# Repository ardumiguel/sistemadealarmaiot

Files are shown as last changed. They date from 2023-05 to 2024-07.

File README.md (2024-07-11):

# Sistema de Alarma IoT

Proyecto presentado en la **Feria Andaluza de Tecnología 2023** y en la **25ª Feria de la Ciencia** del Parque de las Ciencias. Realizado  en el curso de 1 de bachillerato en el IES Alquivira.



El sistema de alarma IoT se compone de cuatro módulos inalámbricos. Cada uno de ellos cuenta con un ESP32 que, a través del protocolo de comunicación inalámbrica “ESP-now”, es capaz de comunicarse con el resto de módulos. Estos son: sensor inalámbrico de puerta o ventana, panel de control, módulo de cámara con sensor de movimiento, y sensor inalámbrico de movimiento. Cabe destacar que los modulos de sensor de movimiento y de puerta o ventana son tan eficientes en cuanto a términos energéticos que su duración de batería es de 18 meses.

## Características

- Control vía Telegram (notificaciones instantáneas, control desde cualquier parte del mundo)
- Lector óptico de huella dactilar
- Módulo de cámara con lente ultra gran angular
- Larga duración de la bateria de los módulos inalámbricos

## Funcionamiento
El funcionamiento está diseñado para que el manejo de la alarma por parte del usuario sea simple e intuitivo.

La alarma puede ser activada vía Telegram, que es la plataforma mediante la cual el sistema notifica al usuario y le envía fotos, o bien manualmente desde el módulo principal. Una vez el sistema está activo, al detectar algún movimiento o la apertura de una puerta, notifica de inmediato al usuario indicando el motivo de la alerta y acompañando el mensaje con una fotografía. 

Para desactivar el sistema, el usuario puede colocar su dedo (previamente registrado) en el lector de huellas incorporado en el módulo principal o en su defecto, enviar un comando por Telegram. El usuario también puede solicitar una fotografía o información acerca del sistema (niveles de batería, estado del sistema, estado de las puertas) en cualquier momento a través de Telegram.
## Librerías necesarias

- [AsyncTelegram2](https://github.com/cotestatnt/AsyncTelegram2)
- [Keypad](https://github.com/Chris--A/Keypad)
- [Adafruit_NeoPixel](https://github.com/adafruit/Adafruit_NeoPixel)
- [Adafruit-Fingerprint-Sensor-Library](https://github.com/adafruit/Adafruit-Fingerprint-Sensor-Library)

## Autor

- [@ardumiguel](https://github.com/ardumiguel)

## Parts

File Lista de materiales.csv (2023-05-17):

Materiales necesarios para el sistema de alarma IoT
Producto | Cantidad | Enlace
ESP32 DEVKIT C - "ESP-32 38 PIN" | 3 | https://www.aliexpress.com/item/32864722159.html
ESP32 CAM | 1 | https://www.aliexpress.com/item/1005003804757059.html
Porgramador micro usb ESP32 CAM | 1 | https://www.aliexpress.com/item/1005003804757059.html
Sensor PIR HC-SR501 | 2 | https://www.aliexpress.com/item/32477783558.html
Cámara OV2640 con lente gran angular | 1 | https://www.aliexpress.com/item/1005002947160929.html
Lector de huellas AS608 | 1 | https://www.aliexpress.com/item/32962793512.html
Batería 18650 | 2 | https://es.aliexpress.com/item/32810252344.html?curPageLogUid=FjRopLjcQ7BE
Zócalo para batería 18650 | 2 | https://www.aliexpress.com/item/32580480645.html
Cargador para baterías 18650 TP4056 | 2 | https://www.aliexpress.com/item/32930640893.html
Caja estanca de conexión | 1 | https://www.psolera.com/es/catalogo/envolventes/cajas-estancas/cajas-estancas-ip65-sin-conos/815/815
Keypad numérico 4x4 | 1 | https://www.aliexpress.com/item/32267354418.html?curPageLogUid=rlNi9NIv6zbv

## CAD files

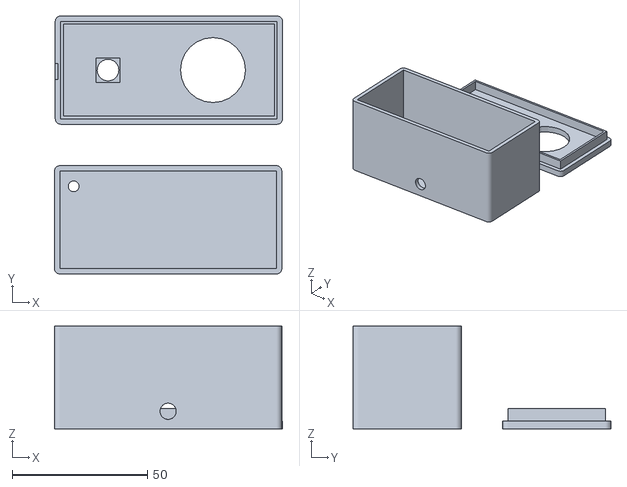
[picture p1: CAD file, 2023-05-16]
Archivos stl/esp32 cam.stl
84.3 x 95.3 x 38.0

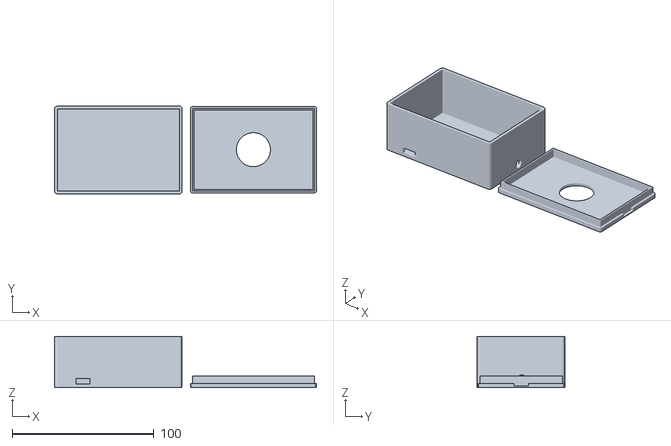
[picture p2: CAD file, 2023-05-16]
Archivos stl/sensor pir.stl
184.8 x 62.0 x 36.0

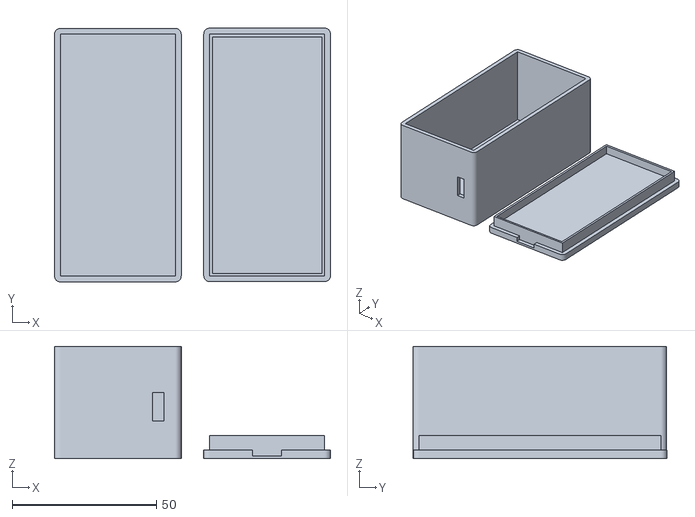
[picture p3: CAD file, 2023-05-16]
Archivos stl/sensor puerta.stl
95.8 x 88.1 x 39.0

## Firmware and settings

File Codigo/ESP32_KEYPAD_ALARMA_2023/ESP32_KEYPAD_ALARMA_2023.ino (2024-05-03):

#include "declaraciones.h"

/*/////////////////////
  INCISO

  LA LOGICA DE LAS PUERTAS ES:

  1 -> ABIERTO
  0 -> CERRADO

  /////////////////////*/


void setup() {
  Serial.begin(115200);
  pixels.Begin();
  pixels.Show();

  wifi_connect();
  delay(500);
  ota_init();
  espnow_init();
  data_init();
  RFID_setup();

  pinMode(sirena, OUTPUT);
  pinMode(sens_puerta, INPUT_PULLUP);



  Serial.println("Programa Iniciado");
}

void loop() {

  led_update();
  handle_keypad(); /*El array 'code' contiene la contraseña escrita*/
  check_code();    /*para actualizar el estado alarma*/
  store_data();
  handle_OTA();
  buzzer_update();
  wifi_keep_alive();
  RFID_update();

  telegram_update();


  /*Variables locales*/
  static byte count = 0;
  static unsigned long t_antes = 0;
  static bool bool_ = false;
  /*Variables locales*/

  if (estado_sistema >= 2 && isopen == false) {
    if (millis() - t_antes >= 1500) {

      bool_ = !bool_;
      if (bool_)
        set_led_color(4, 1500, 50, 50, 50);
      else
        set_led_color(4, 1500, 0, 0, 0);

      t_antes = millis();
    }
  }


  if (isopen == false && estado_sistema >= 2 && digitalRead(sens_puerta) == HIGH) {
    isopen = true;
    isopen_reason = 0;
  }

  if (isopen == true) {

    if (estado_sistema < 2) {
      count = 0;
      bool_ = false;
      isopen = false;
      digitalWrite(sirena, LOW);
      return;  //salimos de este if sin seguir ejecutando este if
    }

    if (count == 0)
      for (int i = 0; i < 8; i++)
        set_led_color(i, 1000, 255, 150, 55);



    if (millis() - t_antes >= 200 && count < 80) {  // Esperamos un poco antes de que suene la sirena

      bool_ = !bool_;
      count++;

#ifdef SEND_PIC
      if (count == 19) {
        /*capturamos una foto*/
        structure senddata{ 0, false };
        esp_now_send(espcamaddress, (uint8_t*)&senddata, sizeof(senddata));
      }
#endif

       if (count == 21) {
        myBot.getNewMessage(msg);  //por si a caso no responde
        //send a mesage
        char mystring[150];
        mystring[0] = '\0';  //strcat empieza a concatenar en el null termination
        strcat(mystring, "\xE2\x9A\xA0 ATENCIÓN \xE2\x9A\xA0\n");
        strcat(mystring, texto_isopen_reason[isopen_reason]);
        myBot.sendTo(CHAT_ID_1, mystring);
        myBot.sendTo(CHAT_ID_2, mystring);


        //enviamos la foto

#ifdef SEND_PIC
        structure senddata{ 0, true };  //id=0, x=true
        esp_now_send(espcamaddress, (uint8_t*)&senddata, sizeof(senddata));
#endif
      }


      if (count >= 20) {
        if (bool_ == true)
          buzzer_tone(buzzer, 450, 200);
        else
          buzzer_tone(buzzer, 600, 200);
      }


      t_antes = millis();
    }

    /***************/

    if (count >= 80) {

      if (millis() - t_antes >= 800) {
        bool_ = !bool_;

        count++;

        if (bool_)
          for (int i = 0; i < 8; i++)
            set_led_color(i, 300, 255, 0, 0);
        else
          for (int i = 0; i < 8; i++)
            set_led_color(i, 300, 0, 0, 0);

        if (count > 108)
          digitalWrite(sirena, LOW);
        else
          digitalWrite(sirena, bool_);


        t_antes = millis();
      }
    }
  } /*end of if(isopen = true)*/
}



void check_code() {

  /*Variables locales*/
  static char last_key;
  static unsigned long t_antes = 0;
  static int count = 0, prev_count = 0;
  static bool b = false;
  /*Variables locales*/


  if (estado_sistema == 0 && (key == 'A' || key == 'B')) {

    if ((digitalRead(sens_puerta) + sens_array[0].x) != 0)  //si hay alguna puerta abierta
      estado_sistema = -1;
    else
      estado_sistema = 1;

    last_key = key;
    key = '\0'; /*vaciamos la variable char para que el usuario tenga que confirmar la tecla*/
    erase_code();
  }

  if (strcmp(keypad_code, pass) == 0 && key == '#' && estado_sistema >= 2) {
    erase_code();
    play_melody(2);
    for (int i = 0; i < 8; i++)
      set_led_color(i, 300, 0, 0, 0);
    estado_sistema = 0;
  }

  else if (strcmp(keypad_code, pass) != 0 && key == '#' && estado_sistema >= 2) {
    erase_code();
    play_melody(0);
    //myBot.sendTo(CHAT_ID, "\xE2\x9A\xA0 ATENCIÓN \xE2\x9A\xA0\nIntento de desactivación detectado");
  }

  /*------------------------------------------------------------------------------------------------*/
  if (estado_sistema == -1) { /*RETARDO de activacion cuando hay algun sensor abierto*/

    if (millis() - t_antes >= 200 && count <= 70) {

      if (count - prev_count >= 4)
        prev_count = count;

      if (count - prev_count == 0) {
        buzzer_tone(buzzer, 1864, 120);
        for (int i = 0; i < 8; i++)
          set_led_color(i, 200, 255, 0, 0);
      } else if (count - prev_count == 1) {
        buzzer_tone(buzzer, 1864, 120);
        for (int i = 0; i < 8; i++)
          set_led_color(i, 200, 0, 0, 0);
      }

      if (digitalRead(sens_puerta) + sens_array[0].x == 0) {  //solo si todos los sensores estan cerrados continuamos
        for (int i = 0; i < 8; i++)
          set_led_color(i, 300, 0, 0, 0);
        count = prev_count = 0;
        estado_sistema = 1;
      }
      count++;
      t_antes = millis();
    }
    if (key || count == 70) { /*Timeout o cualquier tecla*/
      for (int i = 0; i < 8; i++)
        set_led_color(i, 300, 0, 0, 0);
      count = prev_count = 0;
      estado_sistema = 0;
    }
  }


//////////////////////////////////////////////////////////////////////////////////


  if (estado_sistema == 1) { /*RETARDO de activacion*/

    if (millis() - t_antes >= 400 && count <= 23) {

        b = !b;
        if (b == true)
          for (int i = 0; i < 8; i++)
            set_led_color(i, 300, 0, 255, 0);
        else {
          buzzer_tone(buzzer, 2637, 150);
          for (int i = 0; i < 8; i++)
            set_led_color(i, 300, 0, 0, 0);
        }
      
      count++;
      t_antes = millis();
    }

    if (count == 23 || key == 'A' || key == 'B') {
      erase_code();
      count = 0;
      b = false;

      if (last_key == 'A')
        estado_sistema = 2;
      else if (last_key == 'B')
        estado_sistema = 3;

      for (int i = 0; i < 8; i++)
        set_led_color(i, 1000, 0, 0, 0);
      play_melody(1);
      //key = '*'; /*Para que el fp sensor se encienda*/
    } else if (key) {
      erase_code();
      count = 0;
      b = false;
      estado_sistema = 0;
      for (int i = 0; i < 8; i++)
        set_led_color(i, 500, 0, 0, 0);
    }
  }
}


void handle_keypad() {


  static unsigned long t_antes = 0;




  /* 'pos' es la posicion del ultimo numero que hay escrito */


  key = keypad_1.getKey();

  if (key) {
    // key = i;  //hacemoisque key sea constante en el tiempo

    buzzer_tone(buzzer, 4186, 50);
    /*
        if (key == '*') {  //Borrar uno
          keypad_code[pos - 1] = 0;
          pos = pos - 1;
          pos = constrain(pos, 0 , 4);
        }
    */
    if (key == '*') {  // Borrar todo el array
      pos = 0;
      for (int i = 0; i <= 3; i++) {
        keypad_code[i] = 0;
      }
    }

    if (pos <= 3 && key != '#' && key != '*' && key != 'A' && key != 'B') {
      pos += 1;
      pos = constrain(pos, 0, 4);
      keypad_code[pos - 1] = key;
    }
    Serial.println(key);
  }
}

void erase_code() {
  pos = 0;
  for (int i = 0; i <= 3; i++) {
    keypad_code[i] = 0;
  }
}

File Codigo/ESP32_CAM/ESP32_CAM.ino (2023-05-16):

//////////////// Sistema de Alarma IoT - ESP32_CAM /////////////////
/*

Código necesario para el módulo de cámara y sensor PIR

Miguel Rodríguez 2023
Todos los derechos reservados

*/
////////////////////////////////////////////////////////////////////




#include <WiFi.h>
#include <AsyncTelegram2.h>
#include "esp_camera.h"

#include <WiFiClientSecure.h>
WiFiClientSecure client;

#define ssid "SSID"
#define password "PASSWORD"

IPAddress ip(192, 168, 1, 164);
IPAddress gateway(192, 168, 1, 1);
IPAddress subnet(255, 255, 0, 0);
IPAddress dns(192, 168, 1, 1);


// Timezone definition to get time from NTP server
#define MYTZ "CET-1CEST-2,M3.5.0/02:00:00,M10.5.0/03:00:00"
const char* token = "TU_TOKEN";
int64_t CHAT_ID = TU_CHAT_ID;



AsyncTelegram2 myBot(client);
TBMessage msg;


#include <esp_now.h>
bool hasrun = true;
int pcount = 0;
unsigned long t_antes;
#define LAMP_PIN 4



// Structure to receive data
struct structure {
  int id;
  bool x;
};

//ID de los módulos
/*
  ID 0 -> CENTRAL
  ID 1 -> MOVIMIENTO
  ID 2 -> PUERTA INALÁMBRICA 1
  ID 3 -> ESPCAM
*/


structure recvdata;

camera_fb_t* fb;

void OnDataSent(const uint8_t* mac_addr, esp_now_send_status_t status) {
  Serial.print("\r\nLast Packet Send Status:\t");
  Serial.println(status == ESP_NOW_SEND_SUCCESS ? "Delivery Success" : "Delivery Fail");
}

void OnDataRecv(const uint8_t* mac_addr, const uint8_t* incomingData, int len) {
  char macStr[18];
  Serial.print("Packet received from: ");
  snprintf(macStr, sizeof(macStr), "%02x:%02x:%02x:%02x:%02x:%02x", mac_addr[0], mac_addr[1], mac_addr[2], mac_addr[3], mac_addr[4], mac_addr[5]);
  Serial.println(macStr);
  memcpy(&recvdata, incomingData, sizeof(recvdata));
  if (recvdata.id == 0 && recvdata.x == true) {
    hasrun = false;
  }
  if (recvdata.id == 0 && recvdata.x == false) {
    takepicture();
  }
}

void init_espnow() {

  if (esp_now_init() != ESP_OK) {
    Serial.println("Error initializing ESP-NOW");
    return;
  }
  esp_now_register_recv_cb(OnDataRecv);
  Serial.println("ESPNOW init");
}



void setup() {
  pinMode(15, INPUT);
  pinMode(LAMP_PIN, OUTPUT);

  Serial.begin(115200);
  Serial.println();

  // Start WiFi connection
  WiFi.mode(WIFI_AP_STA);
  //WiFi.config(ip, gateway, subnet, dns);
  WiFi.begin(ssid, password);
  while (WiFi.status() != WL_CONNECTED) {
    digitalWrite(LAMP_PIN, HIGH);
    delay(250);
    Serial.print(".");
    digitalWrite(LAMP_PIN, LOW);
    delay(250);
  }
  Serial.println("");
  Serial.println("WiFi connected");
  Serial.println(WiFi.localIP());
  Serial.print("WiFi channel: ");
  Serial.println(WiFi.channel());
  // Sync time with NTP
  configTzTime(MYTZ, "time.google.com", "time.windows.com", "pool.ntp.org");
  client.setCACert(telegram_cert);

  // Set the Telegram bot properies
  myBot.setUpdateTime(300000);
  myBot.setTelegramToken(token);

  // Check if all things are ok
  Serial.print("\nTest Telegram connection... ");
  myBot.begin() ? Serial.println("OK") : Serial.println("NO oK");

  init_camera();
  init_espnow();
}
void loop() {

  myBot.getNewMessage(msg);  //Necesitamos mantener abierta la conexion con telegram abierta

  if (hasrun == false) {

    if (fb != NULL) {
      delay(1000);
      Serial.println("Sending picture");
      myBot.sendPhoto(CHAT_ID, fb->buf, fb->len); /*Hay que llamar a telegram desde el loop para que sea efectivo, si lo llamamos desde otra funcion no va*/
      esp_camera_fb_return(fb);
      fb = NULL;
    }

    hasrun = true;
  }

  if (millis() - t_antes == 20000 && fb != NULL) {
    for (int i = 1; i <= 3; i++)
      esp_camera_fb_return(fb);
    fb = NULL;
  }
}
